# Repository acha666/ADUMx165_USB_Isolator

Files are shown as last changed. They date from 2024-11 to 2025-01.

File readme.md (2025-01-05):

# ADUMx165 USB Isolator

[Chinese Document / 中文文档](./readme.zh.md) | English Document

This is a USB 2.0 High-Speed (480Mbps) isolation module with an onboard 1-to-4 USB HUB, a 1A isolated DC-DC power supply, and support for external auxiliary power input with automatic switching between the two.

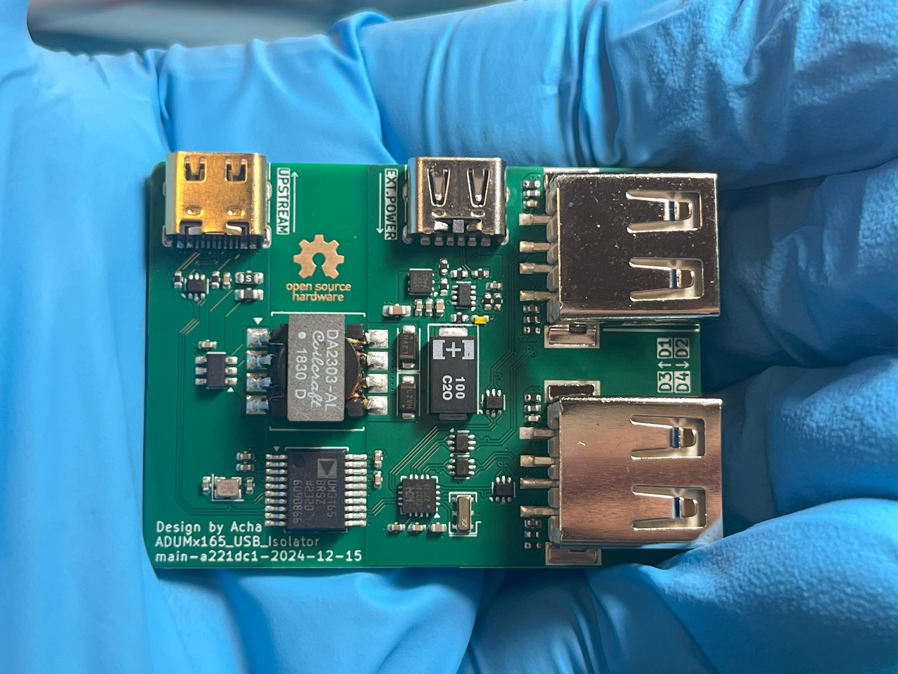
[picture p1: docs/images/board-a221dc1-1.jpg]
Circuit Board Image - 1
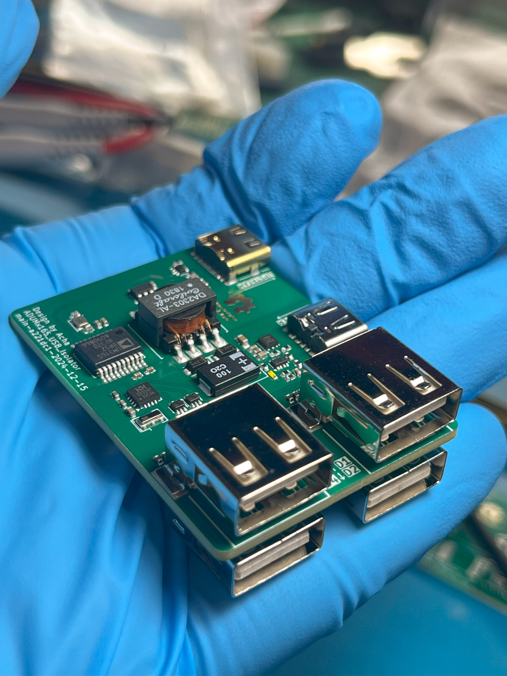
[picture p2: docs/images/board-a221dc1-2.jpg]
Circuit Board Image - 2
 

## Project Status

- [x] Schematic Design
- [x] PCB Design
- [x] PCB Fabrication
- [x] PCB Validation

## Device Overview

- **[ADUM3165](https://www.analog.com/en/products/adum3165.html)/[ADUM4165](https://www.analog.com/en/products/adum4165.html) USB Isolator**: Provides 480Mbps USB isolation with 3.75kV/5.7kV RMS isolation voltage. Pin-to-pin compatible.
- **[SN6505A](https://www.ti.com/product/SN6505A)/[B](https://www.ti.com/product/SN6505B) Transformer Driver**: An isolated DC-DC power controller powered directly from the upstream USB port. The two variants differ in switching frequency.
- **[DA2303-AL](https://www.coilcraft.com/en-us/products/transformers/power-transformers/isolation/da230x/da2303-al) Transformer**: 1:1.5 SMT transformer.
- **[TPS2116](https://www.ti.com/product/TPS2116) Power Multiplexer**: Prioritizes 5V auxiliary power from the downstream port. When unavailable, it automatically switches to the onboard isolated DC-DC power supply.
- **[TLV76701](https://www.ti.com/product/TLV767) LDO**: Regulates the output of the SN6505.
- **[CH334P](https://www.wch-ic.com/products/CH334.html) USB Hub**: A simple USB 2.0 1-to-4 HUB chip.

## Basic PCB Parameters

| Parameter | Value |
|:---:|:---:|
| **Dimensions** | 50.00mm x 36.50mm |
| **Shape** | Rounded Rectangle, r=1.50mm |
| **Finished Thickness** | 1.60mm |
| **Copper Layers** | 4 |
| **Minimum Trace Width**  | 0.12mm |
| **Minimum Trace Space**  | 0.12mm |
| **Minimum Via Hole Diameter** | 0.20mm |
| **Minimum Non-plated Hole Diameter** | >1.00mm |
| **Minimum Via Outer Diameter** | 0.45mm |
| **Minimum Via Inner Diameter** | 0.20mm |
| **Minimum Plated Slot Width** | 0.60mm |
| **Minimum Non-plated Slot Width** | None |
| **Special Manufacturing Processes** | Impedance Control |

## Impedance Control Parameters

### Differential Impedance 1

| Usage | USB 2.0 Signals |
|:---:|:---:|
| **Signal Layers** | L1, L4 |
| **Impedance** | 90Ω |
| **Bottom Reference Layers** | L2, L3 |
| **Top Reference Layer** | None |

| Current Design Parameters | Value |
|:---:|:---:|
| **Trace Width** | 0.12mm |
| **Trace Spacing** | 0.12mm |
| **Copper Thickness** | 1oz/0.5oz |
| **Applicable PCB Stackup** | JLCPCB JLC04161H-3313 |

## Project Description

This project was designed using KiCad 8.06.

GitHub Action CI/CD is deployed, which automatically performs DRC checks and generates manufacturing files (e.g., Gerber files) with each commit.

Manufacturing files are available on the [Release Page](https://github.com/acha666/ADUMx165_USB_Isolator/releases) or the [Workflow](https://github.com/acha666/ADUMx165_USB_Isolator/actions/workflows/kicad-ci.yml).

### Power Design

The module includes a 1A onboard isolated DC-DC power supply and supports external auxiliary power input with automatic switching. The onboard LED indicates that the isolated-side 5V is provided by the onboard DC-DC power supply.

- When using a 5V external auxiliary power supply, the output ports prioritize this external power. The total output capacity depends on the external power supply. Each port is equipped with a self-recovering fuse, limiting current to 500mA.
- When no external power is connected, the onboard isolated DC-DC power supply generates 5V. The total output capacity is limited by both the isolated DC-DC power supply and the upstream USB port.

**Note**: The external auxiliary power supply must not be connected to the same device as the upstream USB port; otherwise, isolation will fail.

#### Updated Note (2024-12-15)

Previously, the TLV76750 was configured for a fixed 5V output. Under heavy load, line losses might reduce the output voltage. It has been replaced with the adjustable TLV76701, with the output voltage set to approximately 5.2V.

### Device Selection Recommendations

#### ADUM3165/4165

According to the [datasheet](https://www.analog.com/media/en/technical-documentation/data-sheets/adum3165-3166.pdf), both are pin-to-pin compatible. The main difference lies in the isolation voltage: 3.75kV for ADUM3165 and 5.7kV for ADUM4165. The test board uses ADUM3165.

#### SN6505A/B

SN6505A has a switching frequency of 160kHz, while SN6505B operates at 420kHz. The test board uses SN6505B.

Per the [datasheet, page 30](https://www.ti.com/lit/ds/sllsep9i/sllsep9i.pdf#page=30), both can be paired with the DA2303-AL transformer. However, SN6505A remains untested.

#### DA2303-AL

**Not recommended for substitution**, as it is optimized for SN6505A/B. Other models may require additional tuning.

#### Ferrite Beads (5 in total)

Based on the schematic, there are 0603 ferrite beads near the upstream input port and 0402 beads near the downstream USB ports (4 in total).

Ferrite beads are used to isolate power noise. Considering that USB ports may carry significant current under extreme conditions, their DC resistance (DCR) should be as low as possible to prevent overheating and voltage drops.

The test board uses the following components:

| Parameter\Model | BLM18SG121TN1D | BLM15PX121SN1D |
|:---:|:---:|:---:|
| Impedance | 120Ω @ 100MHz | 120Ω @ 100MHz |
| Package Size | 0603 | 0402 |
| DCR | 25mΩ | 55mΩ |
| Rated Current | 5A | 3A |

To reduce costs, ferrite beads can be replaced with 0Ω resistors.

#### Tantalum Capacitors

These prevent power instability on the isolated side during external power connection/disconnection. They can be omitted to save costs.

Tantalum capacitors are highly sensitive to overvoltage and polarity reversal, often failing catastrophically. It is recommended to select capacitors with a voltage rating at least twice the operating voltage (5V * 2 = 10V) and ensure correct polarity during soldering (the stripe mark typically indicates the positive terminal). This design uses 16V-rated tantalum capacitors.

### Notes

This document was translated by ChatGPT.

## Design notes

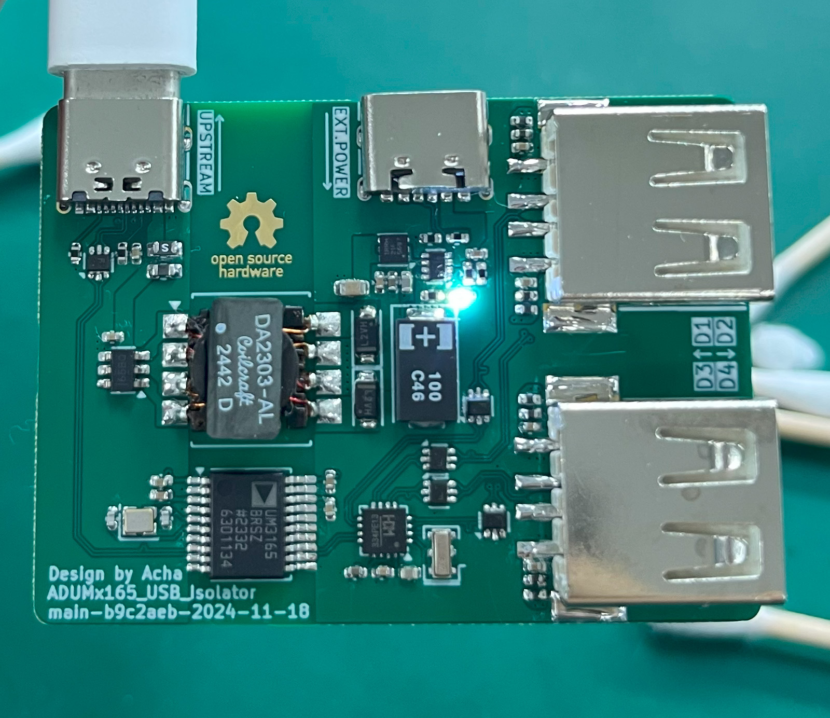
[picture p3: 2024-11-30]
docs/images/board-b9c2aeb.jpg

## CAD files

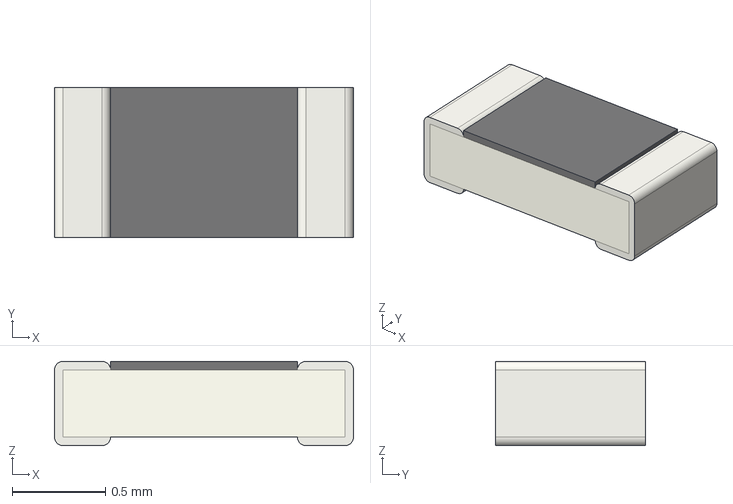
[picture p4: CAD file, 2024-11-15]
ADUMx165_USB_Isolator.3dmodels/Fuse_0603_1608Metric.step
1.60 x 0.8 x 0.45 mm

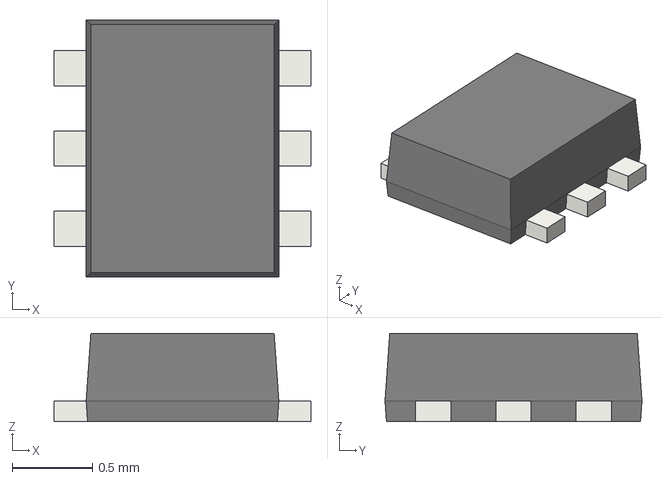
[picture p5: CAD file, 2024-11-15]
ADUMx165_USB_Isolator.3dmodels/SOT-666.step
1.60 x 1.60 x 0.55 mm

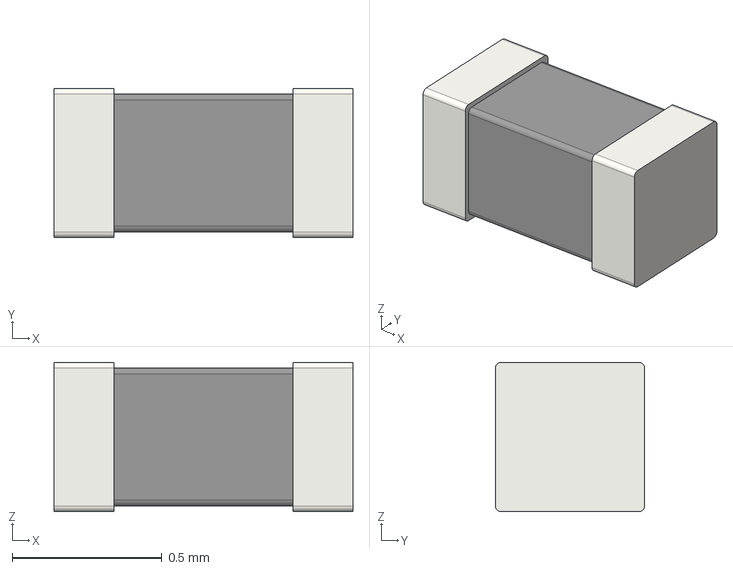
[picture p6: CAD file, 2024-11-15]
ADUMx165_USB_Isolator.3dmodels/L_0402_1005Metric.step
1.00 x 0.5 x 0.5 mm

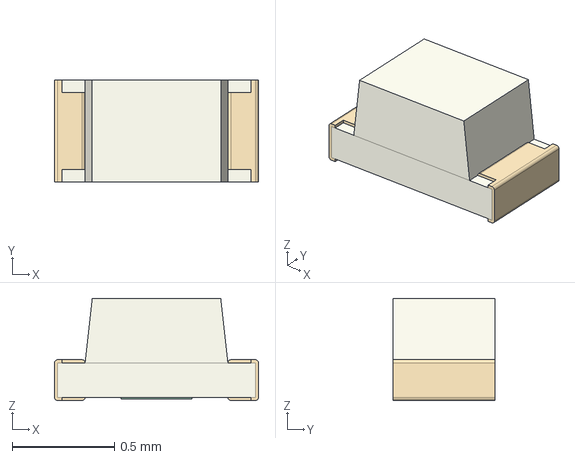
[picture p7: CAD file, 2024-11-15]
ADUMx165_USB_Isolator.3dmodels/LED_0402_1005Metric.step
1.00 x 0.5 x 0.5 mm

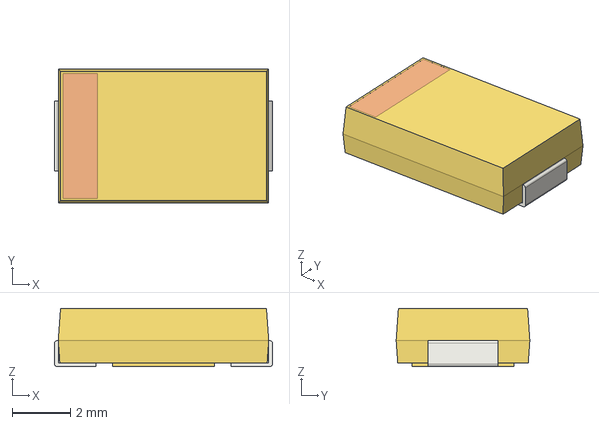
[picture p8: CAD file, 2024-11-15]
ADUMx165_USB_Isolator.3dmodels/CP_EIA-7343-20_Kemet-V.step
7.50 x 4.60 x 2.00 mm

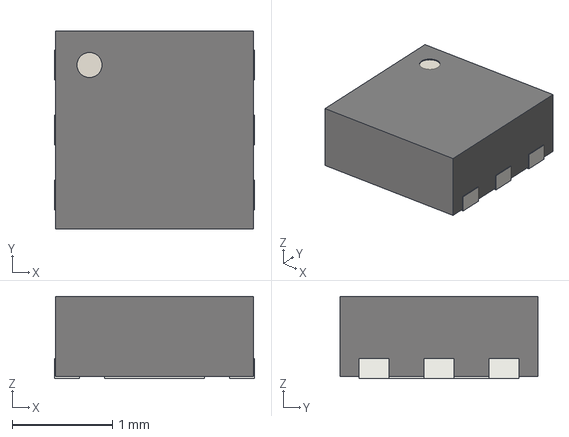
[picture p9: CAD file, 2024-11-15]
ADUMx165_USB_Isolator.3dmodels/WSON-6-1EP_2x2mm_P0.65mm_EP1x1.6mm.step
2.00 x 1.98 x 0.82 mm

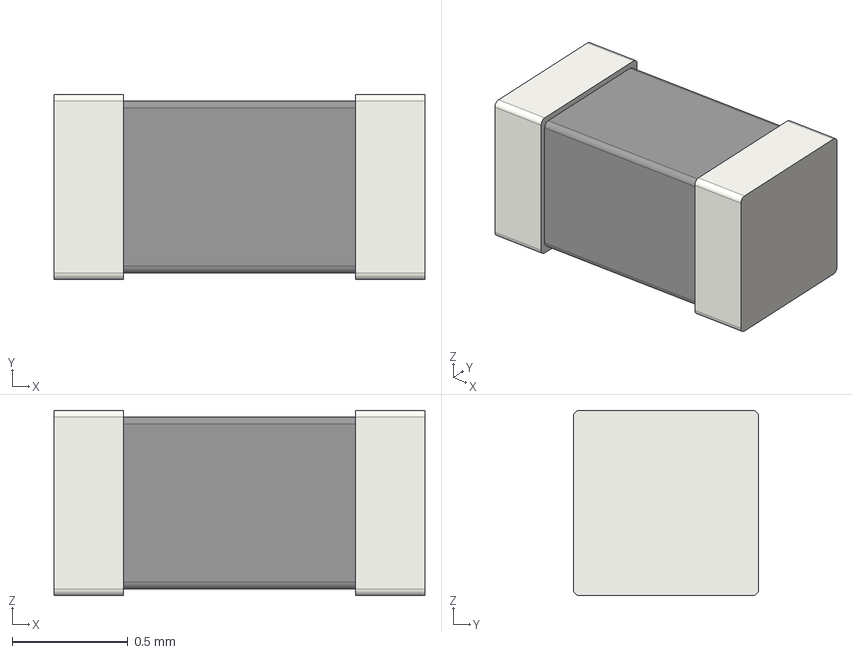
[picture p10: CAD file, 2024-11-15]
ADUMx165_USB_Isolator.3dmodels/L_0603_1608Metric.step
1.60 x 0.8 x 0.8 mm

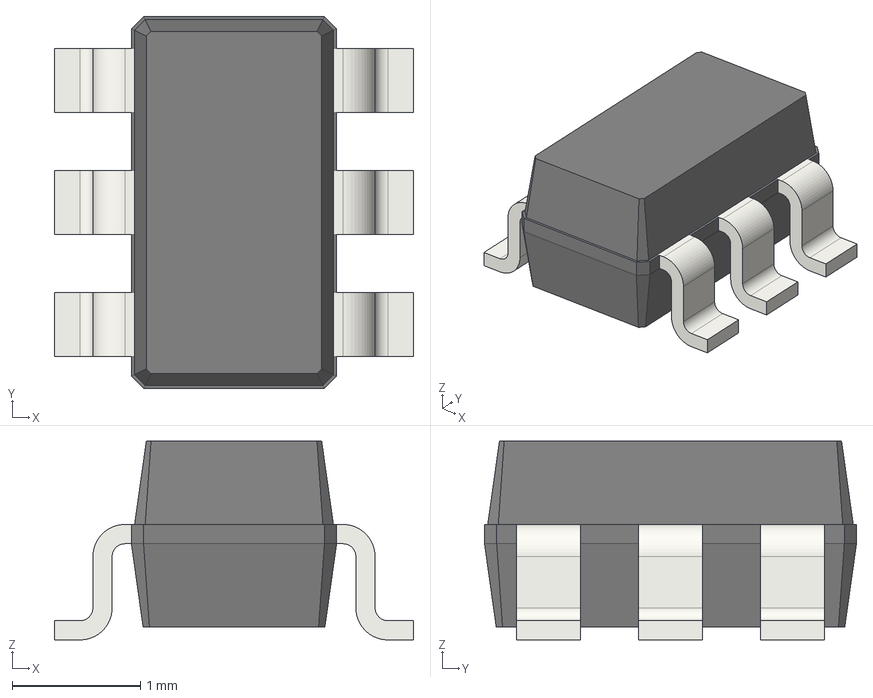
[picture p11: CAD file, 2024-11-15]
ADUMx165_USB_Isolator.3dmodels/SOT-23-6.step
2.80 x 2.90 x 1.55 mm

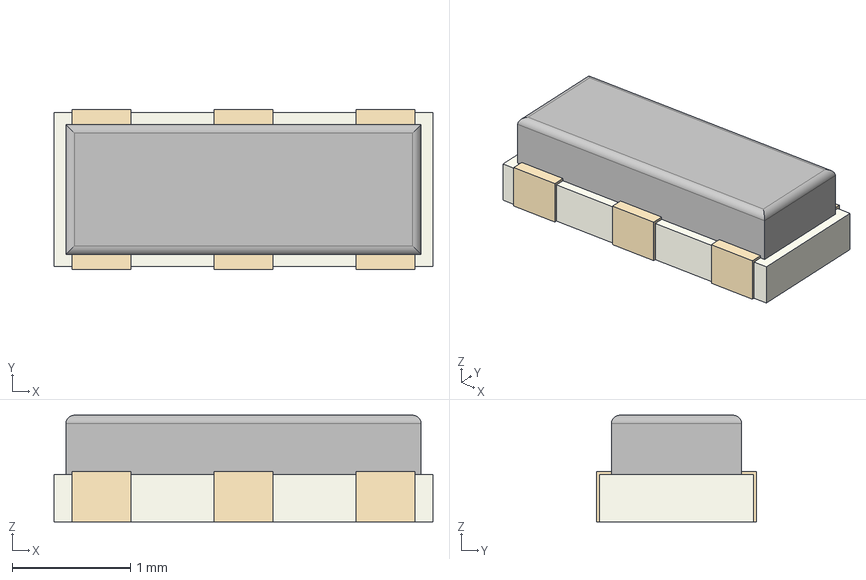
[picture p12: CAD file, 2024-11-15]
ADUMx165_USB_Isolator.3dmodels/Resonator_SMD_Murata_CSTxExxV-3Pin_3.0x1.1mm.step
3.20 x 1.35 x 0.9 mm

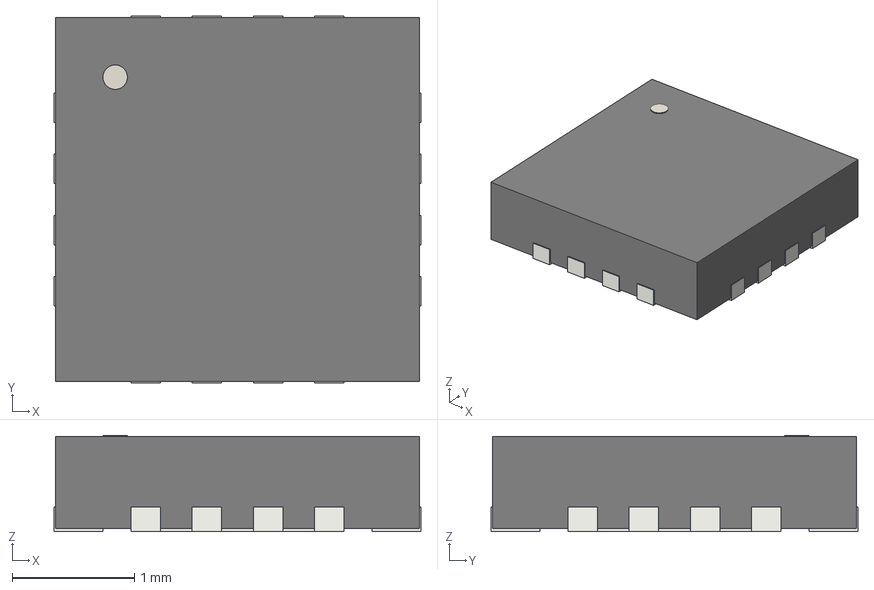
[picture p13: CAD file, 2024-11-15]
ADUMx165_USB_Isolator.3dmodels/QFN-16-1EP_3x3mm_P0.5mm_EP1.7x1.7mm.step
3.00 x 3.00 x 0.785 mm

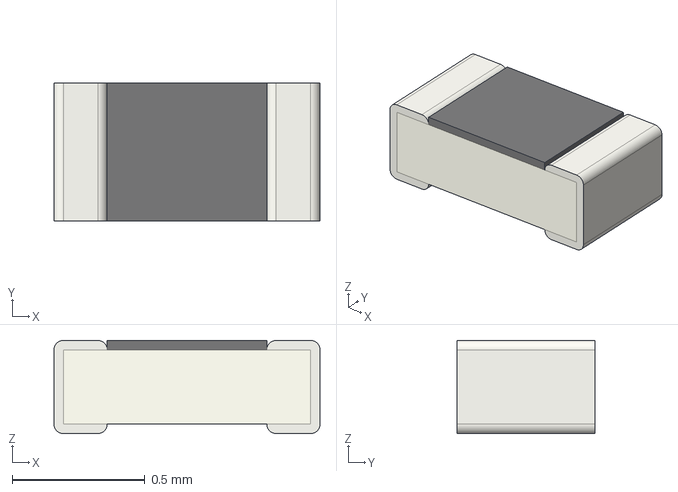
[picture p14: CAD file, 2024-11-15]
ADUMx165_USB_Isolator.3dmodels/Fuse_0402_1005Metric.step
1.00 x 0.52 x 0.35 mm

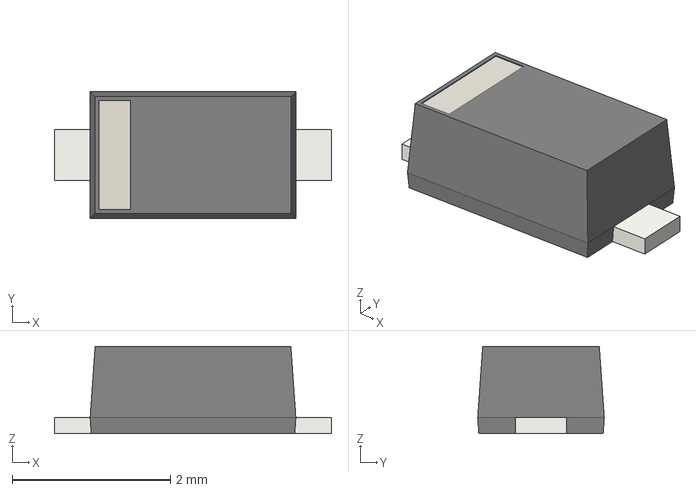
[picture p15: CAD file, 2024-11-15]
ADUMx165_USB_Isolator.3dmodels/D_SOD-123F.step
3.50 x 1.60 x 1.10 mm

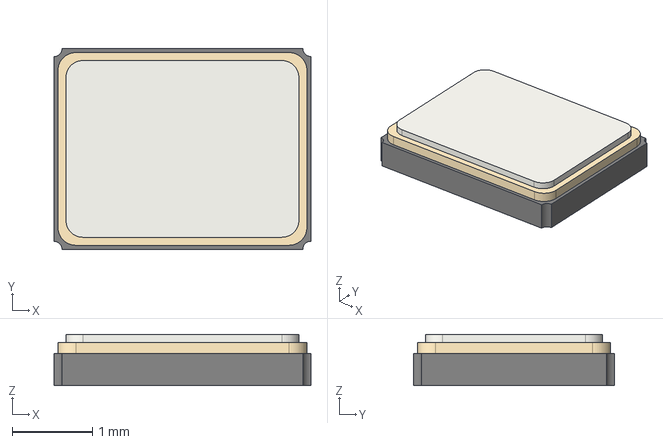
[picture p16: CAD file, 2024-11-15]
ADUMx165_USB_Isolator.3dmodels/Crystal_SMD_3225-4Pin_3.2x2.5mm.step
3.20 x 2.50 x 0.64 mm

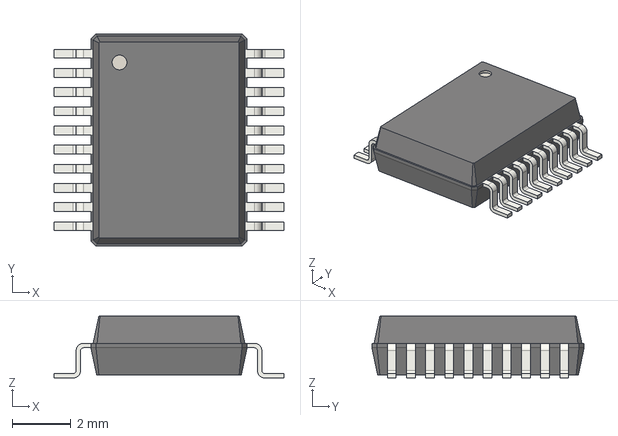
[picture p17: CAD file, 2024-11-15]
ADUMx165_USB_Isolator.3dmodels/SSOP-20_5.3x7.2mm_P0.65mm.step
7.80 x 7.20 x 2.10 mm

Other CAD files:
ADUMx165_USB_Isolator.3dmodels/C_0603_1608Metric.step
ADUMx165_USB_Isolator.3dmodels/C_0402_1005Metric.step
ADUMx165_USB_Isolator.3dmodels/R_0402_1005Metric.step
ADUMx165_USB_Isolator.3dmodels/DRL0008A.stp
ADUMx165_USB_Isolator.3dmodels/Coilcraft-DA2303-AL.STEP
ADUMx165_USB_Isolator.3dmodels/RUX0012A.stp

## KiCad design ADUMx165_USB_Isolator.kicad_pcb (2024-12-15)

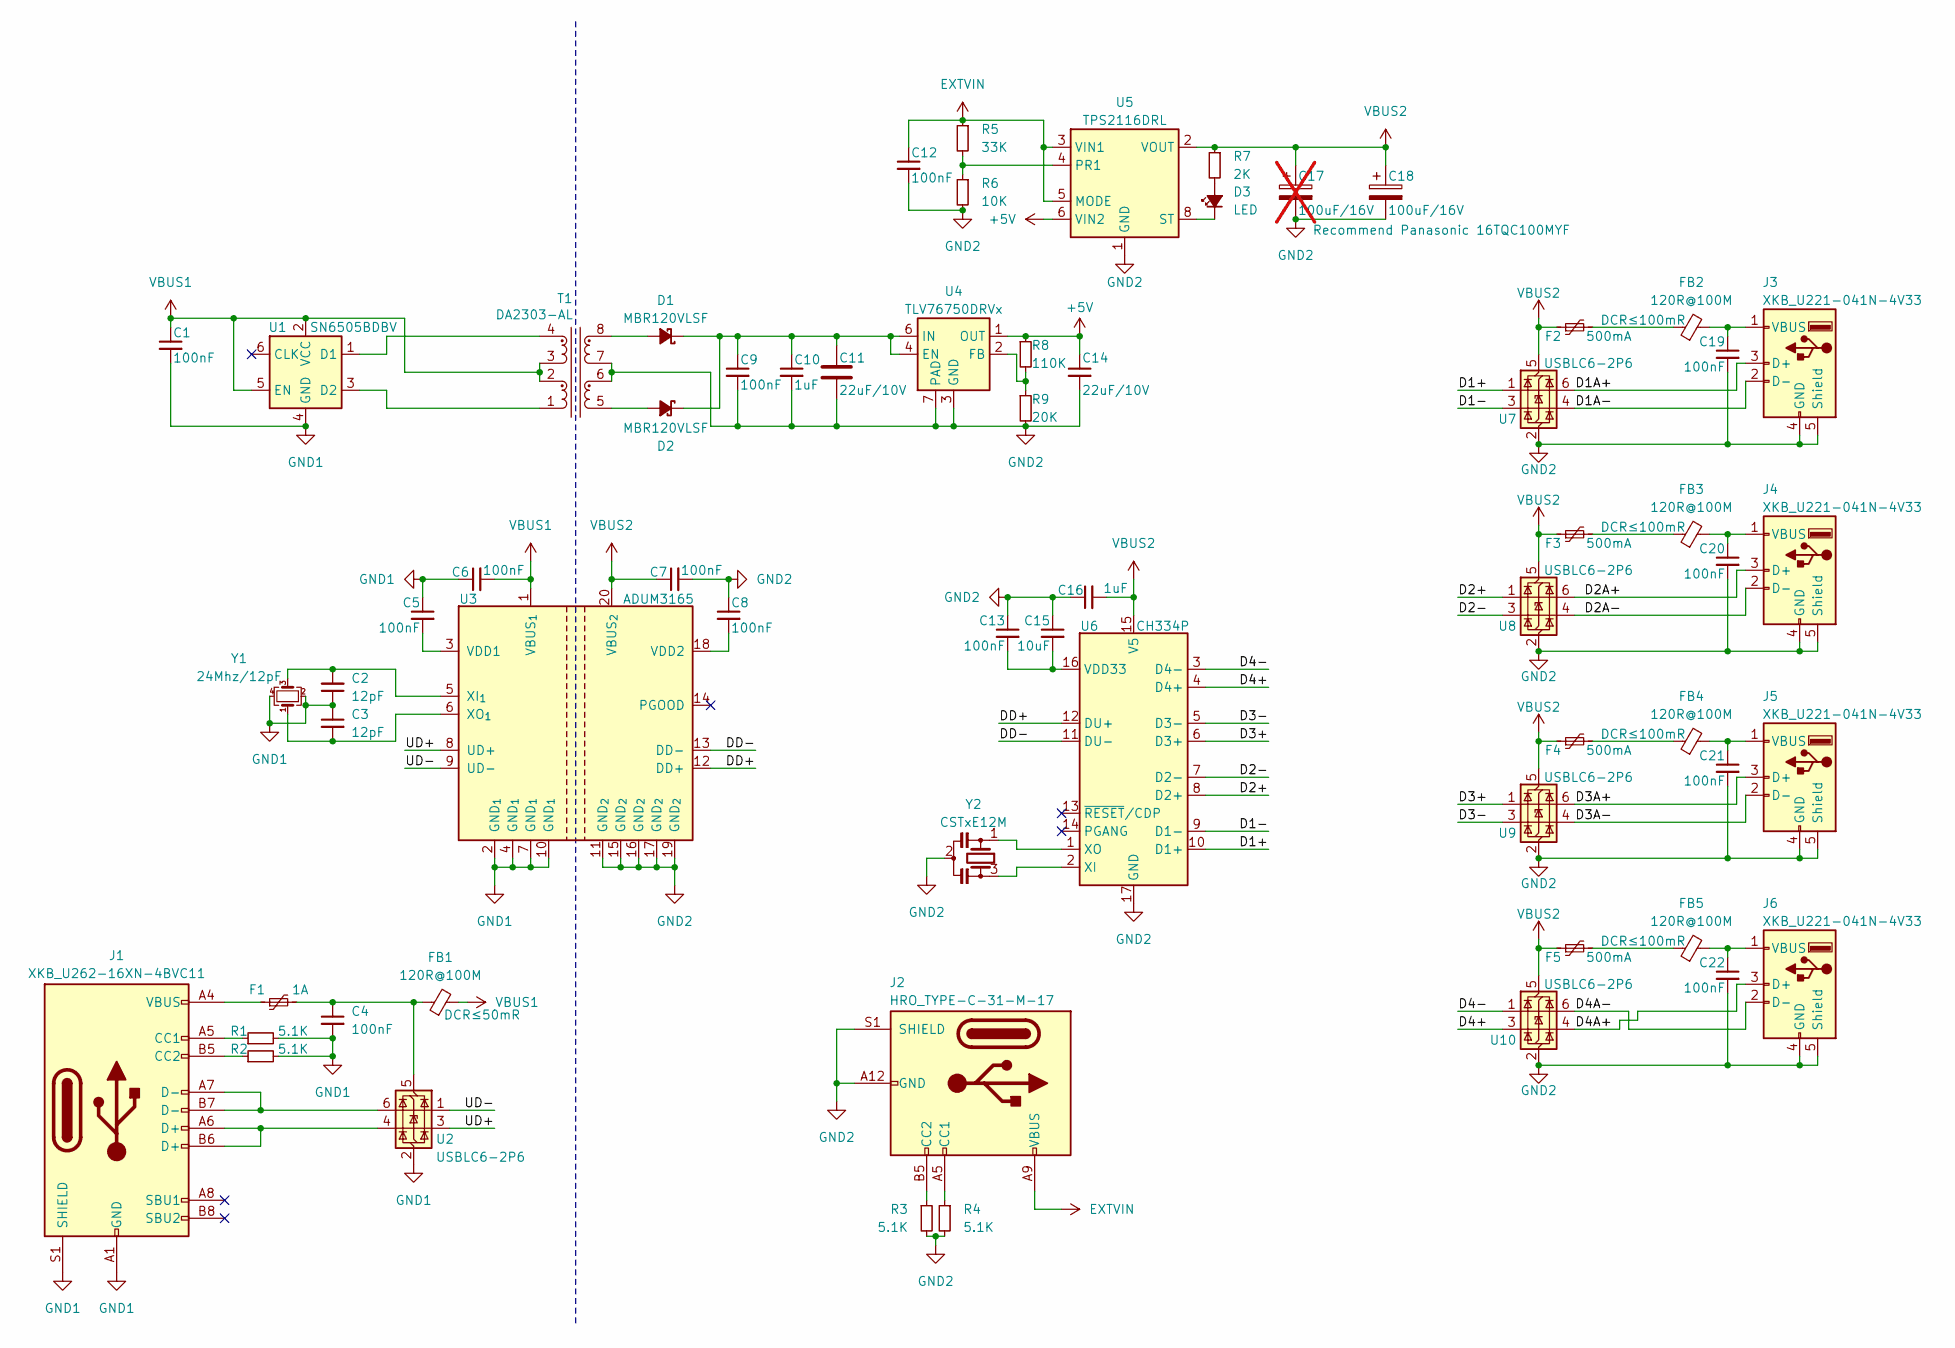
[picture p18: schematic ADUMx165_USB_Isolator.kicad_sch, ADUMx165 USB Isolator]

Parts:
C1, C4, C5, C6, C7, C8, C9, C12, C13, C19, C20, C21, C22: 100nF; C_0402_1005Metric
C2, C3: 12pF; C_0402_1005Metric
C10, C16: 1uF; C_0402_1005Metric
C11: 22uF/10V; C_0603_1608Metric
C14: 22uF/10V; C_0402_1005Metric
C15: 10uF; C_0402_1005Metric
C17: 100uF/16V; CP_EIA-7343-20_Kemet-V; not fitted
C18: 100uF/16V; CP_EIA-7343-20_Kemet-V
D1, D2: MBR120VLSF; D_SOD-123F
D3: LED; LED_0402_1005Metric
F1: 1A; Fuse_0603_1608Metric
F2, F3, F4, F5: 500mA; Fuse_0402_1005Metric
FB1: 120R@100M; L_0603_1608Metric
FB2, FB3, FB4, FB5: 120R@100M; L_0402_1005Metric
J1: XKB_U262-16XN-4BVC11; USB_C_Receptacle_XKB_U262-16XN-4BVC11
J2: HRO_TYPE-C-31-M-17; USB_C_Receptacle_HRO_TYPE-C-31-M-17
J3, J4, J5, J6: XKB_U221-041N-4V33; U221-041N-4V33
R1, R2, R3, R4: 5.1K; R_0402_1005Metric
R5: 33K; R_0402_1005Metric
R6: 10K; R_0402_1005Metric
R7: 2K; R_0402_1005Metric
R8: 110K; R_0402_1005Metric
R9: 20K; R_0402_1005Metric
T1: DA2303-AL
U1: SN6505BDBV; SOT-23-6
U2, U7, U8, U9, U10: USBLC6-2P6; SOT-666
U3: ADUM3165; SSOP-20_5.3x7.2mm_P0.65mm
U4: TLV76750DRVx; WSON-6-1EP_2x2mm_P0.65mm_EP1x1.6mm_ThermalVias
U5: TPS2116DRL; SOT-583-8
U6: CH334P; QFN-16-1EP_3x3mm_P0.5mm_EP1.75x1.75mm
Y1: 24Mhz/12pF; Crystal_SMD_2016-4Pin_2.0x1.6mm
Y2: CSTxE12M; Resonator_SMD_Murata_CSTxExxV-3Pin_3.0x1.1mm

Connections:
+5V: C14.1, R8.1, U4.1 (OUT), U5.6 (VIN2)
/D1+: U6.10 (D1+), U7.1 (I/O1)
/D1-: U6.9 (D1-), U7.3 (I/O2)
/D1A+: J3.3 (D+), U7.6 (I/O1)
/D1A-: J3.2 (D-), U7.4 (I/O2)
/D2+: U6.8 (D2+), U8.1 (I/O1)
/D2-: U6.7 (D2-), U8.3 (I/O2)
/D2A+: J4.3 (D+), U8.6 (I/O1)
/D2A-: J4.2 (D-), U8.4 (I/O2)
/D3+: U6.6 (D3+), U9.1 (I/O1)
/D3-: U6.5 (D3-), U9.3 (I/O2)
/D3A+: J5.3 (D+), U9.6 (I/O1)
/D3A-: J5.2 (D-), U9.4 (I/O2)
/D4+: U6.4 (D4+), U10.3 (I/O2)
/D4-: U6.3 (D4-), U10.1 (I/O1)
/D4A+: J6.3 (D+), U10.4 (I/O2)
/D4A-: J6.2 (D-), U10.6 (I/O1)
/DD+: U3.12 (DD+), U6.12 (DU+)
/DD-: U3.13 (DD-), U6.11 (DU-)
/UD+: U2.3 (I/O2), U3.8 (UD+)
/UD-: U2.1 (I/O1), U3.9 (UD-)
EXTVIN: C12.1, J2.A9 (VBUS), J2.B9 (VBUS), R5.1, U5.3 (VIN1), U5.5 (MODE)
GND1: C1.2, C2.1, C3.1, C4.2, C5.1, C6.1, J1.A1 (GND), J1.A12 (GND), J1.B1 (GND), J1.B12 (GND), J1.S1 (SHIELD), R1.2, R2.2, U1.4 (GND), U2.2 (GND), U3.2 (GND_{1}), U3.4 (GND_{1}), U3.7 (GND_{1}), U3.10 (GND_{1}), Y1.2, Y1.4
GND2: C7.2, C8.1, C9.2, C10.2, C11.2, C12.2, C13.1, C14.2, C15.1, C16.1, C17.2, C18.2, C19.2, C20.2, C21.2, C22.2, J2.A12 (GND), J2.B12 (GND), J2.S1 (SHIELD), J3.4 (GND), J3.5 (Shield), J4.4 (GND), J4.5 (Shield), J5.4 (GND), J5.5 (Shield), J6.4 (GND), J6.5 (Shield), R3.2, R4.2, R6.2, R9.2, T1.6 (OUT2A), T1.7 (OUT1B), U3.11 (GND_{2}), U3.15 (GND_{2}), U3.16 (GND_{2}), U3.17 (GND_{2}), U3.19 (GND_{2}), U4.3 (GND), U4.5 (GND), U4.7 (PAD), U5.1 (GND), U6.17 (GND), U7.2 (GND), U8.2 (GND), U9.2 (GND), U10.2 (GND), Y2.2
unnamed: D1.2 (A), T1.8 (OUT1A)
unnamed: C9.1, C10.1, C11.1, D1.1 (K), D2.1 (K), U4.4 (EN), U4.6 (IN)
unnamed: D2.2 (A), T1.5 (OUT2B)
unnamed: D3.2 (A), R7.2
unnamed: D3.1 (K), U5.8 (ST)
unnamed: F1.1, J1.A4 (VBUS), J1.A9 (VBUS), J1.B4 (VBUS), J1.B9 (VBUS)
unnamed: F2.2, FB2.1
unnamed: F3.2, FB3.1
unnamed: F4.2, FB4.1
unnamed: F5.2, FB5.1
unnamed: J1.A5 (CC1), R1.1
unnamed: J1.B5 (CC2), R2.1
unnamed: J1.A6 (D+), J1.B6 (D+), U2.4 (I/O2)
unnamed: J1.A7 (D-), J1.B7 (D-), U2.6 (I/O1)
unnamed: J2.A5 (CC1), R4.1
unnamed: J2.B5 (CC2), R3.1
unnamed: C19.1, FB2.2, J3.1 (VBUS)
unnamed: C20.1, FB3.2, J4.1 (VBUS)
unnamed: C21.1, FB4.2, J5.1 (VBUS)
unnamed: C22.1, FB5.2, J6.1 (VBUS)
unnamed: T1.4 (OUT1A), U1.1 (D1)
unnamed: T1.1 (OUT2B), U1.3 (D2)
unnamed: C4.1, F1.2, FB1.1, U2.5 (VBUS)
unnamed: C5.2, U3.3 (VDD1)
unnamed: C8.2, U3.18 (VDD2)
unnamed: C2.2, U3.5 (XI_{1}), Y1.3
unnamed: C3.2, U3.6 (XO_{1}), Y1.1
unnamed: R8.2, R9.1, U4.2 (FB)
unnamed: R5.2, R6.1, U5.4 (PR1)
unnamed: C13.2, C15.2, U6.16 (VDD33)
unnamed: U6.2 (XI), Y2.3
unnamed: U6.1 (XO), Y2.1
VBUS1: C1.1, C6.2, FB1.2, T1.2 (OUT2A), T1.3 (OUT1B), U1.2 (VCC), U1.5 (EN), U3.1 (VBUS_{1})
VBUS2: C7.1, C16.2, C17.1, C18.1, F2.1, F3.1, F4.1, F5.1, R7.1, U3.20 (VBUS_{2}), U5.2 (VOUT), U5.7 (VOUT), U6.15 (V5), U7.5 (VBUS), U8.5 (VBUS), U9.5 (VBUS), U10.5 (VBUS)

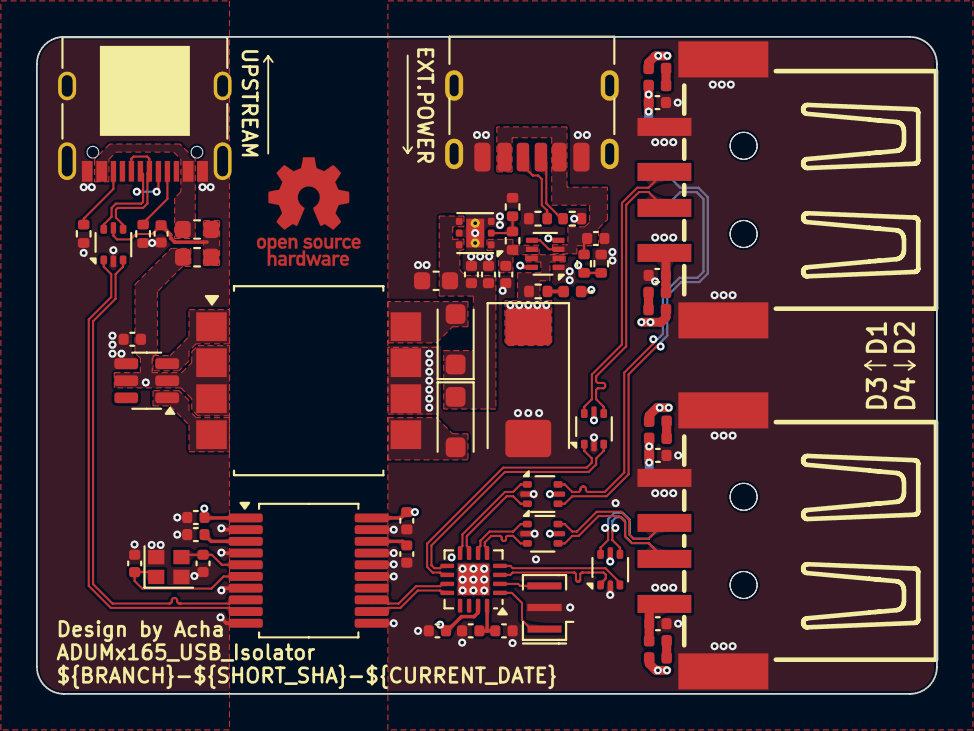
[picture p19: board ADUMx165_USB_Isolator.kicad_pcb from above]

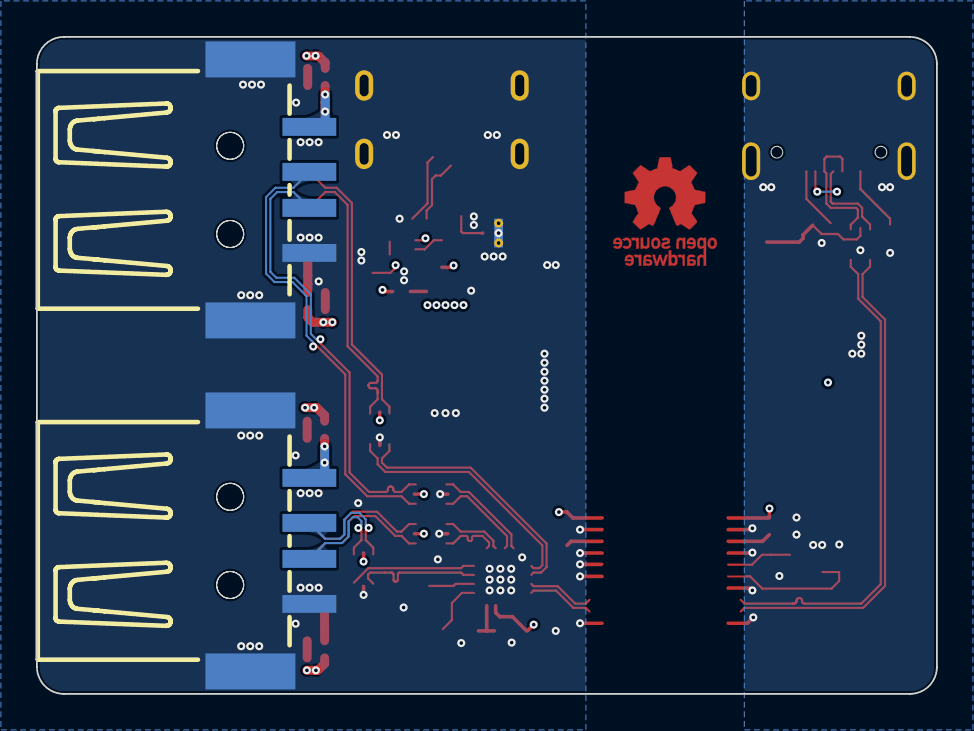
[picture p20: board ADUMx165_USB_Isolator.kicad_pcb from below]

Board: 4 copper layers, 50.0 x 36.5 mm, 62 parts (2 on the bottom side), 58 nets.

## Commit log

2024-11-15 Update workflow Embed 3D models Board shape & silkscreen change
    [ADUMx165_USB_Isolator.kicad_pcb, CP_EIA-7343-20_Kemet-V.step, C_0402_1005Metric.step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]
2024-11-15 Update workflow PCB text objects changes
    [ADUMx165_USB_Isolator.kicad_pcb]
2024-11-15 Update readme.md Update .github/workflows/kicad-ci.yml
2024-11-17 Add GND Vias Update Workflow
    [ADUMx165_USB_Isolator.kicad_pcb, ADUMx165_USB_Isolator.kicad_sch]
2024-11-17 Update FuckJLC
    [ADUMx165_USB_Isolator.kicad_pcb]
2024-11-18 Change drill file export format
2024-11-30 Update readme.md Add Eng translation Add board image Change R7 value to 2K
    [ADUMx165_USB_Isolator.kicad_pcb, ADUMx165_USB_Isolator.kicad_sch]
2024-12-15 Change TLV76750 to TLV76701
    [ADUMx165_USB_Isolator.kicad_pcb, ADUMx165_USB_Isolator.kicad_sch]

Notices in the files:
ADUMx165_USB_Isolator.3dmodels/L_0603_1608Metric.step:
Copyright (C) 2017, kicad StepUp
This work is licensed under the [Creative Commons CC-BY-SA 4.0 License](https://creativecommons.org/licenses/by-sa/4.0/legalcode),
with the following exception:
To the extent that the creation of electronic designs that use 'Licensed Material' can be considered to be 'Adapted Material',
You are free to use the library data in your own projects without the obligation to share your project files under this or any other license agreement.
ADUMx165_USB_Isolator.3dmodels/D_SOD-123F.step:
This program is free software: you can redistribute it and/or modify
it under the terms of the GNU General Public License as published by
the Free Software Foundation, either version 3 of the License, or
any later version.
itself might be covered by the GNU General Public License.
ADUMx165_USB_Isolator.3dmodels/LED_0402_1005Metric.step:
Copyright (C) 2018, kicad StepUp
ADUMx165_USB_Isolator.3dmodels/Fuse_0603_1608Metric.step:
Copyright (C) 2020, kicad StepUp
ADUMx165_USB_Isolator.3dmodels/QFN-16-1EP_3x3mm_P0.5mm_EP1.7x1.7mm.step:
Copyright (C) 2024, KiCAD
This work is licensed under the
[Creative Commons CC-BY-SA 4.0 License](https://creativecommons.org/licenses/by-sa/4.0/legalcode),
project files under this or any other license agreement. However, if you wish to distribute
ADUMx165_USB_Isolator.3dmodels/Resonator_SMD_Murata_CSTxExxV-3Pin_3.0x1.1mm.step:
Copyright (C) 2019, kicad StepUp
